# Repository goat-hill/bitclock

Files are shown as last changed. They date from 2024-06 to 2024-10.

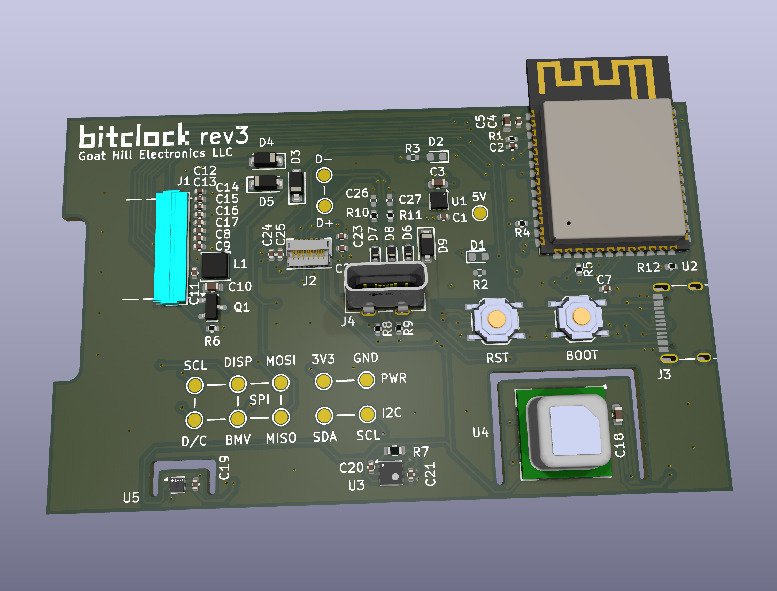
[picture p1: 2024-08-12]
bitclock-pcb/rev3a/pcb.png

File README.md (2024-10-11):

bitclock

# bitclock
Open source e-ink desk companion, clock, and air quality monitor.

Available for purchase in USA @ https://bitclock.io

Bitclock photo

Visit https://bitclock.io/connect to configure your existing device

## Firmware

Source code for ESP32 using the ESP-IDF development framework.

See [bitclock-fw/](bitclock-fw/)

## Website

Next.js web app for [homepage](https://bitclock.io) and [device configurator](https://bitclock.io/connect).

See [bitclock-web/](bitclock-web/)

Web configurator screenshot

## Enclosure

OnShape design, STEP files, and instructions for 3D printing.

See [bitclock-enclosure/](bitclock-enclosure/)

Device CAD screenshot

## PCB

KiCad schematic, board, and JLCPCB ordering files.

See [bitclock-pcb/](bitclock-pcb/)

Bitclock PCB

# Blog posts

- [Advanced ESP32 development with ESP-IDF](https://bitclock.io/blog/esp-idf-vscode)

# Contributing

## Cloning the repo

This repo uses git submodules. Make sure to use `git clone --recursive`.

```sh
git clone --recursive git@github.com:goat-hill/bitclock.git
```

If the repo was previously checked out without `--recursive`, initialize the submodules.

```sh
git submodule init
git submodule update
```

## Pre-commit linting

A single pre-commit config is created for this monorepo. Set up the hooks to get linting on every commit.

```fish
brew install pre-commit
pre-commit install
```

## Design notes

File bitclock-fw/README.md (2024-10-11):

# bitclock firmware

## Bootstrap

### One-time esp-idf setup

[esp-idf](https://github.com/espressif/esp-idf) (the ESP32 development framework) needs to be installed separately before building the firmware.

Bash shell

```fish
brew install cmake ninja dfu-util python@3.12
brew reinstall openssl
git clone -b v5.2.2 --recursive https://github.com/espressif/esp-idf.git
./install.sh esp32s3
source export.sh
```

Fish shell

```fish
brew install cmake ninja dfu-util python@3.12
brew reinstall openssl
git clone -b v5.2.2 --recursive https://github.com/espressif/esp-idf.git
./install.fish esp32s3
source export.fish
```

### Entering esp-idf environment

Bash shell

```sh
source ~/path-to-esp-idf/export.sh
```

Fish shell

```fish
source ~/path-to-esp-idf/export.fish
```

## Target directories

In order to maintain older PCB revision targets, we have separate directories for each PCB revision. Despite most files being shared across targets (via symlinks) we do this because esp-idf doesn't handle multiple targets well. This gives each target it's own build configuration and directory.

```fish
cd target-rev2-esp32s3/
```

To avoid confusing your code editor with duplicate files across targets, it is recommended to open VSCode with a single target as the root directory.

```fish
code .
```

## Build

```fish
idf.py build
```

## Flash

```fish
idf.py flash
```

## Monitor

```fish
idf.py monitor
```

## Debug

```fish
idf.py openocd
```

Then go to VSCode and "Start Debugging" (F5)

## Developer tips

### Bluetooth GATT attributes

If you edit GATT attributes, the web configurator may stop working. This is doing some kind of caching of GATT attributes by service ID.

To resolve the issue, go into Bluetooth settings and "Forget Device", then re-pair it to refresh the GATT cache.

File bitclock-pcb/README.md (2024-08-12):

# bitclock PCB

Each directory includes gerber + BOM files used for ordering from a PCBA service like JLCPCB.

Latest PCB version is [rev3a](rev3a/)

## PCBA ordering scripts

Used for ordering from JLCPCB or MacroFab.

https://github.com/goat-hill/kicad-pcba-scripts

## Revision history

#### rev3a
First version sold on https://bitclock.io/

It does include a few extraneous components that were an attempt to support the unreleased [BMV080](https://www.bosch-sensortec.com/products/environmental-sensors/particulate-matter-sensor/bmv080/) particulate sensor. I may have misinterpreted the preliminary datasheet so feel free to omit that connector and supporting capacitors. It also designs for an option side-USB port that I may omit in the future due to added routing complexity and it is unused.

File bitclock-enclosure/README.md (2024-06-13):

# bitclock enclosure

## CAD design

[OnShape design v6.2](https://cad.onshape.com/documents/f4d7ba303b59b71b8201b0bf/v/8381e401aa08874d26e5d90c/e/d0fdc989a686ce42a3170916)

The 3D printed enclosure STL files can be exported from the "Back plastic" and "Front plastic" parts.

## 3D printing

Print the flat sides down on the bed.

Tested using Prusa Mini+ with PLA and PETG.

Default print settings with 0.2mm Structural mode + input shaping.

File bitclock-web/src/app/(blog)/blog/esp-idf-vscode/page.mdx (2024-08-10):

import NextImage from "next/image";
import { Box, Button, Image, Paper, Title, Kbd } from "@mantine/core";
import InlineVideo from "@/app/(blog)/blog/inline-video";
import InlineImage from "@/app/(blog)/blog/inline-image";
import BitclockBannerImage from "./banner.png";
import BitclockImage from "@/app/img/bitclock.jpg";
import BitclockPcbImage from "@/app/img/pcb.jpg";
import PlatformioImage from "./platformio.png";
import ArduinoCoreImage from "./arduino-core.png";
import FooterImage from "@/app/img/3d-print.jpg";
import GetBitclock from "@/app/(blog)/blog/get-bitclock";

export const metadata = {
  // author: "Brady Law",
  // date: "2024-06-20",
  title: "Advanced ESP32 development with ESP-IDF",
  description: "For electronics projects that outgrow Arduino",
  // bannerImage: BannerImage,
  // tags: ["esp32", "esp-idf", "fimrware"]
};

{
// TODO:
// - Banner image
// - Facebook/Twitter share metadata
// - Post author, date, tags to page
// - Share buttons, Follow on X buttons
// - Code block filenames
// - Static analysis + code completion explanation
// - Interactive debugging explanation
// - Add Bitclock image somwehere
// - Blog navigation and list
}

<Title order={1} mt="xl">
  {metadata.title}
</Title>
<Title order={4} mt="sm" c="dimmed">
  {metadata.description}
</Title>

<Paper shadow="xs" px="md" py="xs" mt="xl">

Many electronics hobbyists begin with the Arduino ecosystem. That's how I got started!

My first project was a tripod mount that could hold an iPhone for filming and pan using a motor. Early iterations used an [Arduino Nano 33 BLE](https://store.arduino.cc/products/arduino-nano-33-ble), a [servo motor](https://www.amazon.com/gp/product/B09BV5D7MD/), and 4x AA batteries.

<InlineVideo
  src="/videos/vscode-arduino.mp4"
  label="Arduino controlling a servo motor"
  loop
  autoplay
/>

When writing firmware for the Arduino Nano, I started with the Android IDE + SDK.

The code for communicating over Bluetooth and controlling the servo fit into a few hundred line `.ino` sketch file.
The wiring was pretty straightforward and only needed a few pins connected. The Arduino [Servo](https://www.arduino.cc/reference/en/libraries/servo/)
library for motor control and [ArduinoBLE](https://www.arduino.cc/reference/en/libraries/arduinoble/) for comms made it easy to implement.

When I finished working on that project, I moved to increasingly complex projects. The [Bitclock](https://bitclock.io) project
needed to connect to an e-ink screen, mount three I2C sensors, and fit into a tiny enclosure.
At this point, I was looking to graduate from the Arduino Nano and hand soldering everything together.

<InlineImage
  src={BitclockImage}
  alt="Bitclock photo"
  label="Bitclock - E-ink clock + air quality monitor"
/>

<GetBitclock />

To meet these requirements, I decided to design a custom PCB (printed circuit board).
By designing a PCB specific to the device, Bitclock electronics could have a smaller footprint that would fit snugly into an enclosure.
Additionally, manufacturing the product at scale would be simplified through PCB assembly services
like 🇨🇳 [JLCPCB](https://jlcpcb.com/), [PCBWay](https://www.pcbway.com/), or 🇺🇸 [MacroFab](https://www.macrofab.com/).

I should disclose that one of my main goals when starting [Bitclock](https://bitclock.io) was to learn custom PCB design,
so my approach was going to end up there anyway!

<InlineImage
  src={BitclockPcbImage}
  alt="Bitclock PCB photo"
  label="Bitclock PCB assembly, featuring an ESP32-S3 microcontroller"
  priority
/>

An early question when designing [Bitclock](https://bitclock.io) was which microcontroller to use.

I settled on the [ESP32-S3](https://www.espressif.com/en/products/socs/esp32-s3) module, which you can see mounted to the top-right corner of the PCB. These ESP32 SoC (system-on-a-chip) modules are popular for a few reasons:

- **All-in-one**: Built-in Wi-Fi, Bluetooth, and flash simplifies PCB design
- **Low price**: Modules starting at [~$1](https://www.digikey.com/en/products/detail/espressif-systems/ESP32-C3-MINI-1-N4/13877574), dev boards for [~$10](https://www.amazon.com/Seeed-Studio-XIAO-ESP32C3-Microcontroller/dp/B0B94JZ2YF/)
- **USB support**: Can be powered, flashed, and debugged over USB
- **SDK**: Extensive development framework with high quality [documentation](https://docs.espressif.com/projects/esp-idf/en/stable/esp32/index.html)
- **Low power**: Can operate in the 10s of mA, sleep in µA range
- **Pre-certification**: [Pre-certified](https://www.espressif.com/en/support/documents/certificates) by FCC and others making products easier to sell

With the [Bitclock](https://bitclock.io) project, my firmware grew to [thousands of lines](https://github.com/goat-hill/bitclock/tree/master/bitclock-fw/main) and many files.
The firmware needed to render graphics for a display, communicate over bluetooth + Wi-Fi, communicate with sensors.
These features needed to multi-task on a single core and meet the constrained memory & flash of the ESP32.

While you can technically write code for ESP32 using the Arduino IDE + SDK, I settled on an alternative approach for this project
using Espressif's [**ESP-IDF framework**](https://github.com/espressif/esp-idf).

### Switching to ESP-IDF

Technically, you _can_ program an ESP32 using Arduino IDE & SDK.

The generic Arduino toolchain supports different hardware platforms through [**Arduino Cores**](https://github.com/arduino/ArduinoCore-API).
Each Arduino Core implements the standard APIs like [Serial](https://www.arduino.cc/reference/en/language/functions/communication/serial/) and [Wire](https://www.arduino.cc/reference/en/language/functions/communication/wire/).
In the case of ESP32 devices, Espressif
actively maintains the [arduino-esp32](https://github.com/espressif/arduino-esp32) core implementation.

Under the hood, the [arduino-esp32](https://github.com/espressif/arduino-esp32) core is largely implemented using the [**ESP-IDF framework**](https://github.com/espressif/esp-idf).
The ESP-IDF framework was developed specifically for ESP32 SoCs, and has many features and APIs specific to that family of devices.

<InlineImage
  src={ArduinoCoreImage}
  alt="Demonstration of Arduino leveraging ESP-IDF"
  label="arduino-esp32 is implemented using ESP-IDF"
/>

This brought about a major design decision for [Bitclock](https://bitclock.io). Continue using the generic and familiar Arduino SDKs, or switch to the manufacturer's ESP-IDF framework?

- ✅ Arduino is a familiar SDK
- ✅ Arduino is compatible with different hardware
- ✅ Arduino can be lower effort to bootstrap using the IDE
- ❌ Arduino core abstraction layer means more code. Extra code could lead to unnecessary complexity and bugs.
- ❌ Arduino cores cannot make ESP32-specific assumptions. This could make precise device control more difficult.

For the Bitclock project, hardware cross-compatibility was not a priority. Instead, hardware _control_ was more important especially given the hardware constraints of:

- 400kB memory
- 8 MB flash
- Single core to multi-task display + sensors + networking

On the other hand, the ESP-IDF framework offers equivalent [high and low level APIs](https://docs.espressif.com/projects/esp-idf/en/latest/esp32/api-reference/index.html), and is very well documented.

Some of the ESP-IDF features Bitclock leverages include:

- [freertos](https://docs.espressif.com/projects/esp-idf/en/stable/esp32/api-reference/system/freertos.html) - Multi-threading for better display performance
- [ota](https://docs.espressif.com/projects/esp-idf/en/stable/esp32/api-reference/system/ota.html) - OTA firmware updates via Wi-Fi or bluetooth
- [partitions](https://docs.espressif.com/projects/esp-idf/en/stable/esp32/api-guides/partition-tables.html) - For custom layouts of flash memory
- [bt](https://docs.espressif.com/projects/esp-idf/en/stable/esp32/api-reference/bluetooth/index.html) - Bluetooth + BLE applications

Given the above, I decided to use ESP-IDF directly and bypass the Arduino abstraction.

### Switching to VSCode

While I had enjoyed using the Arduino IDE previously, it no longer seemed the obvious choice given the ESP-IDF choice. VSCode was the general code editor I used the most, and has many appealing features:

- Strong IDE support for [C and C++ development](https://marketplace.visualstudio.com/items?itemName=ms-vscode.cpptools)
- Performant and streamlined text editor
- As opposed to Arduino IDE: better support for files and directories
- Free. Corporate backing by Microsoft
- Integrates Github Copilot which can [speed up development](https://github.blog/2022-09-07-research-quantifying-github-copilots-impact-on-developer-productivity-and-happiness/)

In order to make the switch to VSCode, it was necessary to ensure that I would have replacements for a few crucial Arduino IDE features:

1. Compile + flash + serial log monitoring
2. Static code analysis + code completion
3. Interactive GDB debugging

[PlatformIO](https://platformio.org/) is a popular VSCode extension that supports all of these features, so I experimented with that before ultimately deciding not to use it and instead configure VSCode manually.

#### Evaluating PlatformIO

On paper, PlatformIO supported all the features I wanted for embedded development in VSCode. I'd be able to compile, flash, debug, and get static analysis of my code.

However, after installing the extension I was less enthused. I was greeted with a landing page showing news, social links, and project creation wizards. It's certainly a personal preference, but PlatformIO was delivering me an entire IDE-within-IDE when I was looking for a few basic debugging and code highlighting features.

<InlineImage
  src={PlatformioImage}
  alt="PlatformIO screenshot"
  label="VSCode after PlatformIO extension installed"
/>

Fortunately, there is an alternative way to get the functionality I desired using only VSCode, the [C/C++ extension by Microsoft](https://marketplace.visualstudio.com/items?itemName=ms-vscode.cpptools), and the [ESP-IDF](https://github.com/espressif/esp-idf) CLI toolchain.

### ESP-IDF toolchain setup

The ESP-IDF toolchain includes the SDK, as well as a [command line front-end](https://docs.espressif.com/projects/esp-idf/en/stable/esp32/api-guides/tools/idf-py.html) for `build`, `flash`, and `monitor`.
If you use PlatformIO it likely installs it for you, but since we're doing things manually we'll install it ourselves.

Follow the [instructions from Espressif here](https://docs.espressif.com/projects/esp-idf/en/stable/esp32/get-started/linux-macos-setup.html).

On macOS, you'll need create a directory to install the SDK to and the process goes something like this:

```sh
brew install cmake ninja dfu-util python3
git clone -b v5.3 --recursive https://github.com/espressif/esp-idf.git
./install.fish esp32s3
source export.sh
```

Make sure to read the [latest docs](https://docs.espressif.com/projects/esp-idf/en/stable/esp32/get-started/linux-macos-setup.html) for up-to-date installation instructions.

### ESP-IDF project bootstrapping

With the toolchain now installed, create a separate directory to house the source code of your new project.

You can use ESP-IDF frontend to create a barebone project for you:

```sh
source ~/your/path/to/esp-idf/export.sh
idf.py create-project example
```

This will create a directory structure with the following:

```text
├── CMakeLists.txt          Top-level build configuration
├── main
│   ├── CMakeLists.txt      Defines main build target + dependencies
│   └── example.c           Main run function for app
```

Make sure to tell ESP-IDF what device you are building for:

```sh
idf.py set-target esp32s3
```

With that complete, build and run is a simple via the CLI:

- `idf.py build`
- `idf.py flash`
- `idf.py monitor`

### Static analysis + code completion

The ESP-IDF CLI tool solves build + run, but for VSCode to be a real IDE™️ it needs to know where to look for ESP-IDF libraries referenced by your code.

We'd need code static analysis to get library auto-completion, CMD+click to jump to function definitions, and a red squiggly underlines when we add a bug.

<InlineVideo
  src="/videos/vscode-completion.mp4"
  autoplay
  loop
  label="Auto-completion from ESP-IDF SDK"
/>

First, make sure you have the [C/C++ extension](https://marketplace.visualstudio.com/items?itemName=ms-vscode.cpptools) by Microsoft installed.

Then we can [configure IntelliSense](https://code.visualstudio.com/docs/cpp/customize-default-settings-cpp) by adding a `.vscode/c_cpp_properties.json` file to the root of the project. VSCode will read this to configure the extension.

Here's an example that worked for Bitclock's ESP32-S3 on macOS:

```json
{
  "env": {
    "esp-version": "esp-13.2.0_20240530"
  },
  "configurations": [
    {
      "name": "esp32s3",
      "compilerPath": "${HOME}/.espressif/tools/xtensa-esp-elf/${esp-version}/xtensa-esp-elf/bin/xtensa-esp-elf-gcc",
      "compileCommands": "${workspaceFolder}/build/compile_commands.json",
      "includePath": [
        "${HOME}/.espressif/tools/xtensa-esp-elf/${esp-version}/xtensa-esp-elf/xtensa-esp-elf/include/**",
        "${HOME}/code/esp-idf/components/**",
        "${workspaceFolder}/**"
      ],
      "browse": {
        "path": [
          "${HOME}/.espressif/tools/xtensa-esp-elf/${esp-version}/xtensa-esp-elf/xtensa-esp-elf/include/**",
          "${HOME}/code/esp-idf/components/**",
          "${workspaceFolder}/**"
        ],
        "limitSymbolsToIncludedHeaders": false
      }
    }
  ],
  "version": 4
}
```

It does the following:

- Sets `.compilerPath` to point to the GCC compiler used for the project
- Sets `.compileCommands` to hint to IntelliSense the specific arguments for how each file was last compiled
- Sets `.includePath` to include the core libraries for IntelliSense, [component](https://docs.espressif.com/projects/esp-idf/en/stable/esp32/api-guides/build-system.html) libraries, and your project workspace
- Sets `.browse.path` to include same libraries for the ["Tag Parser" of VSCode](https://code.visualstudio.com/docs/cpp/faq-cpp#_what-is-the-difference-between-includepath-and-browsepath)

Make sure the paths match the locations of ESP-IDF's install location and `~/.espressif` workspace for your system. See the ESP-IDF [tools.json](https://github.com/espressif/esp-idf/blob/master/tools/tools.json) to see what version you should be pointing to. For example, ESP32-S3 uses the `xtensa-esp-elf` compiler while ESP32-C3 uses `riscv32-esp-elf`.

To be honest, I'm not entirely sure how critical each of these fields is to IntelliSense but I do know that in its entirety the configuration worked for my project!
I used the [Espressif's VSCode extension](https://github.com/espressif/vscode-esp-idf-extension/blob/master/docs/C_CPP_CONFIGURATION.md) as a guide (yet another VSCode extension that I opted to skip and configure manually 🧘).

### Interactive debugging

Last but not least, we'd like to have GDB functionality within VSCode. The `C/C++` extension we've already installed supports this but we need to tell it how to connect.

<InlineVideo
  src="/videos/vscode-debug.mp4"
  autoplay
  loop
  label="ESP32 interactive debugging using OpenOCD"
/>

For Bitclock, the following [debugging configuration](https://code.visualstudio.com/docs/cpp/launch-json-reference) worked by this file to your project's `.vscode/launch.json`:

```json
{
  "version": "0.2.0",
  "configurations": [
    {
      "name": "esp-openocd",
      "type": "cppdbg",
      "request": "launch",
      "program": "${workspaceFolder}/build/example.elf",
      "MIMode": "gdb",
      "miDebuggerPath": "/full/path/to/.espressif/tools/xtensa-esp-elf-gdb/14.2_20240403/xtensa-esp-elf-gdb/bin/xtensa-esp32s3-elf-gdb",
      "cwd": "${workspaceFolder}",
      "setupCommands": [
        { "text": "target extended-remote :3333" },
        { "text": "set remote hardware-watchpoint-limit 2" },
        { "text": "mon reset halt" },
        { "text": "maintenance flush register-cache" },
        { "text": "thb app_main" }
      ]
    }
  ]
}
```

Make sure `.miDebuggerPath` points to the correct ESP-IDF toolchain for this project (see `tools.json` tip from above). Also ensure `.program` points to the `.elf` build of your project.

Once setup, connect your ESP32 hardware, flash it with the latest version of your app, and start the local [OpenOCD](https://openocd.org/) server. This will start a debugging connection over USB with your device:

```sh
idf.py openocd
```

The last step is to connect VSCode to your debugging session. Open the **Run & Debug Panel** (on macOS: <Kbd>⌘</Kbd> + <Kbd>Shift</Kbd> + <Kbd>D</Kbd>), then the click the ▶️ button to start debugging (<Kbd>F5</Kbd>).
VSCode allows you to visually set breakpoints, inspect memory, and the usual debugging IDE features you'd expect.

### Parting thoughts

For projects that grow too complex for the Arduino ecosystem, consider switching to ESP-IDF & VSCode.
If you take that path, I hope this write-up proves a helpful resource in getting things going.

<InlineImage src={FooterImage} alt="Bitclock photo" />

There is more I'd love to share from working on this project. Topics include:

- PCB and 3D printed enclosure design
- Multi-threaded apps with freertos
- Working with e-ink displays and LVGL graphics

If you've got feedback, or want to see anything specifically described further, don't hesitate to reach out at [brady@bitclock.io](mailto:brady@bitclock.io)!

And if you're interested in the gadget that inspired this post, consider ordering a Bitclock!
Either use it as clock + air quality monitor, or write your own apps. The code is [open source on GitHub](https://github.com/goat-hill/bitclock).

<GetBitclock />

Happy hacking...

--Brady

</Paper>

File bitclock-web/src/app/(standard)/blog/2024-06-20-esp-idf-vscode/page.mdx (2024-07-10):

import NextImage from "next/image";
import { Image } from "@mantine/core";
import BannerImage from "./banner.png";
import { Box, Paper, Title } from "@mantine/core";
import InlineVideo from "@/app/(standard)/blog/inline-video";
import BitclockImage from "./banner.png";

export const metadata = {
  // author: "Brady Law",
  // date: "2024-06-20",
  title: "ESP32 development with ESP-IDF & VSCode",
  description: "Tips for projects that outgrow the Arduino SDK",
  // bannerImage: BannerImage,
  // tags: ["esp32", "esp-idf", "fimrware"]
};

{
// TODO:
// - Banner image
// - Facebook/Twitter share metadata
// - Post author, date, tags to page
// - Share buttons, Follow on X buttons
// - Code block filenames
// - Static analysis + code completion explanation
// - Interactive debugging explanation
// - Add Bitclock image somwehere
// - Blog navigation and list
}

<Title order={1} mt="xl">
  {metadata.title}
</Title>
<Title order={4} mt="sm" c="dimmed">
  {metadata.description}
</Title>

<Image
  component={NextImage}
  src={BitclockImage}
  w="100%"
  width={928}
  h="auto"
  alt="Bitclock photo"
  radius="md"
  fit="contain"
  mt="md"
/>

<Paper shadow="xs" px="md" py="xs" mt="xl">
Hobbyist electronics projects are increasingly turning to the ESP32 SoC (System-on-a-Chip) to control their devices. [Bitclock](https://github.com/goat-hill/bitclock) is no exception, and features an [ESP32-S3-WROOM-1](https://www.digikey.com/en/products/detail/espressif-systems/ESP32-S3-WROOM-1-N8/15200089) module mounted to the board.

These modules are popular for a number of reasons:

- **Simplicity**: Built-in Wi-Fi, Bluetooth, and flash on a single module
- **Low price**: Modules for [~$1](https://www.digikey.com/en/products/detail/espressif-systems/ESP32-C3-MINI-1-N4/13877574), dev boards for [~$10](https://www.amazon.com/Seeed-Studio-XIAO-ESP32C3-Microcontroller/dp/B0B94JZ2YF/)
- **SDK**: Extensive development framework and high quality [documentation](https://docs.espressif.com/projects/esp-idf/en/stable/esp32/index.html)
- **Low power consumption**: Can operate in the 10s of mA or sleep in µA
- **Pre-certification**: [Pre-certified](https://www.espressif.com/en/support/documents/certificates) by FCC and others so it's easier to sell

### Outgrowing the Arduino SDK

Most ESP32 tutorials begin with installing the Arduino IDE. It's popular because it only takes a few steps to get a running "Hello World" or blinking LED. The IDE automatically downloads an ESP32 SDK and has a simple but comprehensive interface for getting started.

However, more complex ESP32 projects can quickly overwhelm the constraints of single Arduino sketch file. The Arduino IDE + SDK is efficient for bootstrapping projects but is **not the best fit for more advanced ESP32 projects.**

When exploring development environments for Bitclock, I had a few objectives:

#### 1. Remove unnecessary abstractions

When using the Arduino IDE, you are tied to using the [arduino-esp32](https://github.com/espressif/arduino-esp32) SDK and the Arduino [programming language](https://www.arduino.cc/reference/en/).

The [arduino-esp32](https://github.com/espressif/arduino-esp32) SDK is an abstraction on top of the ESP32-specific [ESP-IDF](https://github.com/espressif/esp-idf) SDK. While there are some advantages to using an abstract Arduino SDK that can port to non-ESP32 board types, complex applications will benefit from using the [ESP-IDF](https://github.com/espressif/esp-idf) framework directly and optimizing for the hardware selceted for the project.

The ESP-IDF framework is packed with features and is extremely well documented. Some features [Bitclock](https://github.com/goat-hill/bitclock) leverages include:

- [freertos](https://docs.espressif.com/projects/esp-idf/en/stable/esp32/api-reference/system/freertos.html) - Multi-threading and better display performance
- [ota](https://docs.espressif.com/projects/esp-idf/en/stable/esp32/api-reference/system/ota.html) - OTA firmware updates via Wi-Fi or bluetooth
- [partitions](https://docs.espressif.com/projects/esp-idf/en/stable/esp32/api-guides/partition-tables.html) - For custom layouts of flash memory
- [bt](https://docs.espressif.com/projects/esp-idf/en/stable/esp32/api-reference/bluetooth/index.html) - Bluetooth + BLE applications

By using a generic IDE instead of Arduino, we can start using the ESP-IDF SDK instead.

#### 2. Use a popular IDE

VSCode is already a popular choice for backend, web, and embedded software development. It has strong IDE support for development in C and C++. It is free, extremely performant, and the backing of Microsoft to keep it working well. It also integrates with Github Copilot which can [speed up certain development tasks](https://github.blog/2022-09-07-research-quantifying-github-copilots-impact-on-developer-productivity-and-happiness/).

And last but not least, it makes it easy for your project to have more than one source file! 😀

Before switching to using ESP-IDF + VSCode environment, I wanted to validate that the following developer features would still be available:

1. **Simple build + run + monitor**
2. **Static analysis + code completion**
3. **Interactive debugging**

In the sections below, I'll show how this functionality is preserved.

#### \* - A note on PlatformIO

[PlatformIO](https://platformio.org/) is a popular project for ESP32 development within VSCode.

I first evaluated using that, but I did not find that it met the first requirement of _Minimize abstractions_. The VSCode extension it requires adds a lot of visual and functional bloat to the VSCode editor that I found unnecessary through the setup described later in this post.

### ESP-IDF toolchain setup

To start a project with ESP-IDF, you'll first need to install the ESP-IDF toolchain. Follow the [instructions on the Espressif website here](https://docs.espressif.com/projects/esp-idf/en/stable/esp32/get-started/linux-macos-setup.html).

On macOS, you'll need create a directory to install the SDK to and the process goes something like this:

```sh
brew install cmake ninja dfu-util python@3.12 openssl
git clone -b v5.2.2 --recursive https://github.com/espressif/esp-idf.git
./install.fish esp32s3
source export.sh
```

Make sure to select the latest release version of ESP-IDF, the board you are using in place of `esp32s3` and read their docs for the latest instructions.

### Basic project setup

Create a separate new directory to house your project source code.

See the [ESP-IDF Hello World](https://github.com/espressif/esp-idf/tree/v5.2.2/examples/get-started/hello_world) example for the basic project setup.

The file structure will start with the following:

```text
├── CMakeLists.txt
├── pytest_hello_world.py      Python script used for automated testing
├── main
│   ├── CMakeLists.txt
│   └── hello_world_main.c
```

Once your project is created, and the ESP-IDF environment is active via `source ~/esp-idf/export.sh`, build and run is a simple via the CLI:

- `idf.py build`
- `idf.py flash`
- `idf.py monitor`

The [Hello World example](https://github.com/espressif/esp-idf/tree/v5.2.2/examples/get-started/hello_world) does a good job of giving the basics of how an ESP-IDF project is organized, so this post will focus on other topics.

### Static analysis + code completion

<InlineVideo
  src="/videos/vscode-completion.mp4"
  autoplay
  loop
  label="Auto-completion from ESP-IDF SDK"
/>

```json
{
  "env": {
    "esp-version": "esp-13.2.0_20230928"
  },
  "configurations": [
    {
      "name": "esp32s3",
      "compilerPath": "${HOME}/.espressif/tools/xtensa-esp-elf/${esp-version}/xtensa-esp-elf/bin/xtensa-esp-elf-gcc",
      "compileCommands": "${workspaceFolder}/build/compile_commands.json",
      "includePath": [
        "${HOME}/.espressif/tools/xtensa-esp-elf/${esp-version}/xtensa-esp-elf/xtensa-esp-elf/include/**",
        "${HOME}/code/esp-idf/components/**",
        "${workspaceFolder}/**"
      ],
      "browse": {
        "path": [
          "${HOME}/.espressif/tools/xtensa-esp-elf/${esp-version}/xtensa-esp-elf/xtensa-esp-elf/include/**",
          "${HOME}/code/esp-idf/components/**",
          "${workspaceFolder}/**"
        ],
        "limitSymbolsToIncludedHeaders": false
      },
      "defines": ["BOARD_TARGET=2"]
    }
  ],
  "version": 4
}
```

### Interactive debugging

<InlineVideo
  src="/videos/vscode-debug.mp4"
  autoplay
  loop
  label="GDB interactive debugging using OpenOCD"
/>

```sh
idf.py openocd
```

```json
{
  "version": "0.2.0",
  "configurations": [
    {
      "name": "esp-openocd",
      "type": "cppdbg",
      "request": "launch",
      "program": "${workspaceFolder}/build/bitclock.elf",
      "MIMode": "gdb",
      "miDebuggerPath": "/Users/bradylaw/.espressif/tools/xtensa-esp-elf-gdb/12.1_20231023/xtensa-esp-elf-gdb/bin/xtensa-esp32s3-elf-gdb",
      "cwd": "${workspaceFolder}",
      "setupCommands": [
        { "text": "target extended-remote :3333" },
        { "text": "set remote hardware-watchpoint-limit 2" },
        { "text": "mon reset halt" },
        { "text": "maintenance flush register-cache" },
        { "text": "thb app_main" }
      ]
    }
  ]
}
```

Show how to attach in VSCode, set breakpoints, print values.

### Custom PCB design tips

Do not add a USB-to-UART, it is built-in to ESP32-S3 + ESP32-C3

Buttons are not required for switching to BOOT mode.

Don't forget strapping pins and pull-up resistors.

### Multi-target repo organization

```text
├── bitclock-fw/
│   ├── components/
│   ├── main/
│   ├── target-board-v1/
│   ├── target-board-v2/
│   ├── partitions.csv
│   └── sdkconfig.defaults
```

#### bitclock-fw/target-board-v2/

**Source files**

```text
├── .vscode/
│   ├── c_cpp_properties.json
│   ├── launch.json
│   └── settings.json
├── CMakeLists.txt
├── dependencies.lock
├── sdkconfig
```

**Symlinks**

```text
├── components/
├── main/
├── partitions.csv
```

**Auto-generated files**

```text
├── sdkconfig
├── dependencies.lock
```

### Parting thoughts

In this post, we outlined how to set up a development environment for an ESP32 project using ESP-IDF and VSCode instead of the more restrictive Arduino IDE.

In future posts we'll go into:

- Multi-threaded apps with freertos
- Working with e-ink displays and LVGL graphics
- Designing custom PCBs to fit 3D printed enclosures

In the meantime, send any comments or development tips to brady@bitclock.io!

Also if you're interested in a cute desk clock + air quality monitor for your desk that inspired this post, order one at [bitclock.io](https://bitclock.io).
It's completely open source and a fun hackable device to get started with ESP32 development.

</Paper>

by Brady Law

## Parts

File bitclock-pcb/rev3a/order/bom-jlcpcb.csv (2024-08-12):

Comment | Designator | Footprint | JLCPCB Part #
TestPoint | TP1,TP2,TP3,TP4,TP5,TP6,TP7,TP8,TP9,TP10,TP11,TP12,TP13 | TestPoint_Pad_D1.5mm
100nF | C4,C8,C19 | C_0402_1005Metric | C1525
0Ω | R10,R11 | R_0402_1005Metric | C17168
4.7µF | C10 | C_0603_1608Metric | C19666
AO3400A | Q1 | SOT-23 | C20917
4.7Ω | R7 | R_0603_1608Metric | C23164
2.2µF | C3 | C_0603_1608Metric | C23630
10kΩ | R1,R12 | R_0402_1005Metric | C25744
5.1kΩ | R4,R5,R8,R9 | R_0402_1005Metric | C25905
10pF | C7 | C_0402_1005Metric | C32949
1µF | C1,C2,C9,C11,C12,C13,C14,C15,C16,C17,C20,C21,C22,C23,C24,C25 | C_0402_1005Metric | C52923
1N5819HW-7-F | D3,D4,D5,D9 | D_SOD-123 | C82544
10µF | C5,C18 | C_0603_1608Metric | C96446
470mΩ | R6 | R_0402_1005Metric | C158958
600mA 10uH ±20% SPH3010H100MT | L1 | L_Sunlord_SWPA3010S | C279861
SW_Push | SW1,SW2 | SW_Push_1P1T_XKB_TS-1187A | C318884
FH34SRJ-24S-0.5SH | J1 | HRS_FH34SRJ-24S-0.5SH_99_ | C324726
LESD5D5.0CT1G | D6,D7,D8 | D_SOD-523 | C383211
ECT818001568 | J2 | FPC-SMD_ECT818001568 | C711417
TLV76733DRVT | U1 | WSON-6-1EP_2x2mm_P0.65mm_EP1x1.6mm | C2867572
SHT40-AD1B-R2 | U5 | Sensirion_DFN-4_1.5x1.5mm_P0.8mm_SHT4x_NoCentralPad | C2909890
ESP32-S3-WROOM-1-N8 | U2 | ESP32-S3-WROOM-1 | C2913198
TYPE-C 16PLC-H10.0 | J4 | TYPE-C-TH_16PLC-H10.0 | C3151747
SGP41-D-R4 | U3 | XDCR_SGP41-D-R4 | C3659325
SCD40-D-R2 | U4 | Sensirion_SCD4x-1EP_10.1x10.1mm_P1.25mm_EP4.8x4.8mm | C3659421

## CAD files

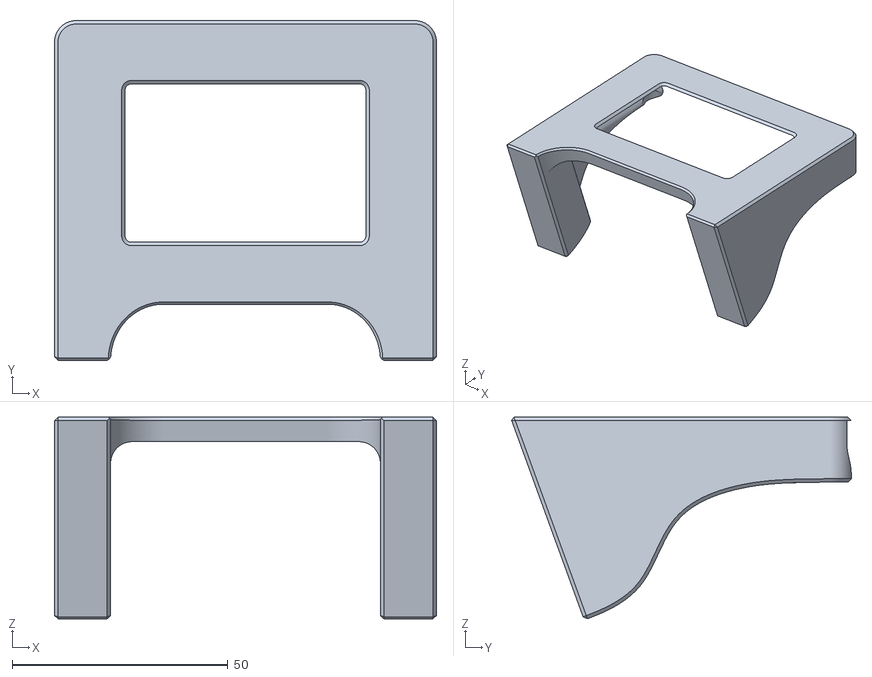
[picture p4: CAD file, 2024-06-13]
bitclock-enclosure/v6.2/front.stl
88.5 x 78.7 x 46.7

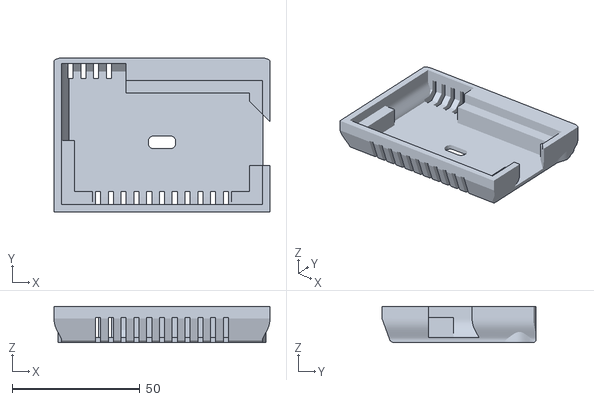
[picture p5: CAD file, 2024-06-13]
bitclock-enclosure/v6.2/back.stl
84.5 x 60.2 x 14.1

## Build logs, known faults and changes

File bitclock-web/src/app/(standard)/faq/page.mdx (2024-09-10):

### How do I power my Bitclock?

The device is powered via a USB-C port, any USB cable that can connect with USB-C on one side should work.

It is recommended that you power it from an always-on power source: either a wall adapter from an old iPhone, a desktop, etc.

Device is very low power so any power source rated for at least 250mA @ 5V (> 1.25W) will suffice.

### How do I set up my new Bitclock?

If assembling the device yourself, the e-ink display may still have a protective film so make sure to peel that off before inserting it into the enclosure.

Once assembled, power the device with a USB-C cable and connect to it by visiting [bitclock.io/connect](/connect) in Google Chrome on a desktop/laptop.

From there, input your Wi-Fi credentials so the device can connect to the internet and sync clocks + weather.

The configuration tool uses Web Bluetooth to communicate to the Bitclock. Make sure Bluetooth on your computer is enabled.

Many browsers, including most mobile browsers, [don't support Web Bluetooth](https://developer.mozilla.org/en-US/docs/Web/API/Web_Bluetooth_API#browser_compatibility), so you'll need to use Google Chrome for macOS/Windows.

### Is it difficult to 3D print the enclosure myself?

No, in fact it should be very easy to print on a properly tuned 3D printer! You can find the STL files and printing tips on [GitHub](https://github.com/goat-hill/bitclock/tree/master/bitclock-enclosure).

It takes around 2 hours on a Prusa Mini+, and the print is relatively simple with no supports. I've tested many prints with PETG and the prints have been reliable.

Make sure the Z adjustment for the first layer is [properly tuned](https://help.prusa3d.com/article/live-adjust-z_112427) since that will be the visible front of the Bitclock.

### How do I make a custom clockface app?

This is a bit complicated at the moment, but in the future I hope to make this much more approachable and documented! Here is some info in the meantime.

Bitclock leverages [FreeRTOS](https://www.freertos.org/) for multi-tasking. A display task is responsible for controlling the e-ink display.

The display task is defined in [eink_display.c](https://github.com/goat-hill/bitclock/blob/master/bitclock-fw/main/tasks/eink_display.c), and utilizes [LVGL](https://github.com/lvgl/lvgl) to render what appears on the display.

LVGL views are defined in the [lvgl/](https://github.com/goat-hill/bitclock/tree/master/bitclock-fw/main/lvgl) directory.

If your clockface requires networking or some other background work, I suggest creating a separate task for that logic. See the [weather.c](https://github.com/goat-hill/bitclock/blob/master/bitclock-fw/main/tasks/weather.c) task as an example of making regular background network requests.

### How accurate are the sensors?

Bitclock uses three Sensirion factory calibrated sensors. See below for their reported accuracy.

Device self-heating impacts temperature and relative humidity readings.
To mitigate this, temperature and relative humidity are adjusted based on consistent [offsets](https://github.com/goat-hill/bitclock/blob/a495f9582fb3601ba604b6d4db3fd6bbdfef9350/bitclock-fw/main/tasks/sht4x.c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) observed during testing.

If Bitclock is not in normal operation (consistently on and connected to Wi-Fi) you may observe inaccurate measurements. If you tweak the code and the device uses more or less power, this can also slightly impact sensor accuracy.

VOC, NOx, and CO2 readings are relative sensors that auto-calibrate over time to the surrounding environment. The CO2 sensor, for example, expects "fresh air" levels of CO2 at least once per week and calibrates to that level.

Sensor details from Sensirion:

- [SHT40 ±1.8% / max. ±3.5% RH Digital humidity and temperature sensor](https://sensirion.com/products/catalog/SHT41)
- [SCD40 CO₂ accuracy of ±(50 ppm + 5% MV) @400-2000 ppm](https://sensirion.com/products/catalog/SCD40)
- [SGP41 VOC and NOx sensor](https://sensirion.com/products/catalog/SGP41)

### Can the device be battery powered?

At the moment, no. The enclosure, PCB, and software all assume USB as the source of power.

The device runs at a pretty lower power usage (\~0.25W) so it could be tweaked in the future.

### Why does it not have a PM2.5 particulate sensor?

Wildfires are a growing concern here in California and I'd love to add a particulate sensor.

Unfortunately, particulate sensors like the [Plantower PM2.5 sensor](https://learn.adafruit.com/pm25-air-quality-sensor/overview) have very large form factors and
I decided to omit them from the current design.

My hope is in the future there will be cheap sensors with a smaller form factor, like the unreleased [BMV080](https://www.bosch-sensortec.com/products/environmental-sensors/particulate-matter-sensor/bmv080/).

In fact, there is a port on the Bitclock based on preliminary datasheets from that sensor! If it ever releases and is accurate, I'd like to integrate it in the future.

### Why is this thing so expensive?

The e-ink display and CO2 sensor components alone cost $30 per unit. Alternative CO2 sensors products typically cost well over $100.

There's also low volume PCB assembly costs, as well as 3D printing.

### Can I place the Bitclock somewhere not at a desk?

Of course, although keep in mind the display size, viewing angle, and font sizes were picked with a desk setup in mind.

At longer viewing distances beyond a few feet, it can be difficult to read some of the smaller text.

### Does it have a backlight?

No, the display requires an external light source. In future versions I'll consider adding a backlight but the current version doesn't include one.

### Does the device integrate with Apple HomeKit / Google Home / Alexa...

Not yet, but I'd like to add that with a future software update!

It would be great to integrate this with home automation to turn on fans, AC, etc.

### What is the e-ink display like, and why does it use one?

Similar to an Amazon Kindle, the device has an e-ink display that operates by reflecting external light vs emitting light itself. This gives the device a
very natural aesthetic that looks more like paper as opposed to a bright and distracting display.

Each pixel is 1 bit color (black or white), although you can simulate some grays through dithering.

The display can be updated in two ways: a "fast update" which immediately updates only certain pixels or a "full refresh" which blinks the entire display between
black and white for the cleanest update.

While "fast updates" are the least distracting, but over time they can lead to "ghosting" where pixels are not cleanly reset. That's where an occassional "full refresh" where the screen blinks between black and white to cleanly reset the display and show the clearest image.

### How does the device feel?

The 3D printed enclosure is extremely light, under 0.2 lbs or ~60g. I've tried to make an attractive looking device, but it can still have an unavoidable "prototype" feel due to the nature of 3D printing as opposed injection molding or using heavier materials.

There are some visible layer layer lines, and the front and back have a textured surface from the textured plate it prints on.

### Other questions, comments, feedback?

Please ask! Reach me at brady@bitclock.io

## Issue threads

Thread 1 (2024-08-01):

Modify SCD40 calibration periods #46

babldev, 2024-08-01:
Currently set_automatic_self_calibration_initial_period defaults to 44 hours. But that assumes one read every 5 minutes and we read every 5 seconds.

So for "default" behavior we should probably multiply this value by 60. Needs to be sent on boot.

Also scale set_automatic_self_calibration_standard_period in the same fashion

babldev, 2024-08-04:
Nevermind, this only applies to single shot measurement modes. we're not using that

Closed 2024-08-04.

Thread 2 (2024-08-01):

Bluetooth attribute for inverted colors

babldev, 2024-08-01:
Currently it's a build flag only. Give a bluetooth option so you can easily switch to dark mode.

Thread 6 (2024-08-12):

Mainboard link is 404

meron1122, 2024-08-12:
Hi, mainboard link from readme.md causes 404.

babldev, 2024-08-12:
I went ahead and uploaded the rev3a design today https://github.com/goat-hill/bitclock/tree/master/bitclock-pcb/rev3a

I wasn't sure if I wanted to immediately open source the PCB design until I finished selling a first batch here https://bitclock.io/order

But given I don't ship outside of the USA so I don't have to work through the regulatory stuff I decided to open source it in case others want to order! I included ordering files from JLCPCB.

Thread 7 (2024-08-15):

ESP32-C3 version with 18650 battery + charger

handmade0octopus, 2024-08-15:
Hello!
I must say you inspired me a little. Was thinking of making project like this for very long time but never had time to figure which eInk screens would work best and get drivers working.

I spent the night and big part of today to get basic schematic in.

Ideas that I incorporated:
1. Biggest change is swap MCU to one that is less power hungry - namely ESP32-C3 which also has smaller footprint. We utilize 99% of pins on current design with 1 spare pin for extra stuff.

2.  Use single 4.2v cell that will be power source with boost converter + timer controller that is selectable with dip switches to allow for configuration to wakeup at different intervals (from every ~45s up to 30 min - but it can be easily extended from 1s to 2h) or disable sleep completely if needed. Question there is if sensors need some time after powerup to get accurate readings, but because they will be disabled board will have neutral temperature. In general this should allow for super low power draw.

3. USB-C allows for safe charging of the battery. I based design of TP4056 module with overvoltage + undervoltage protection of battery, we can use analog input to measure battery voltage - there is also an option to put input for solar panel as charger will allow for that. Typical 6V solar panel should be enough although I never played with them so any tips are appreciated. Charging current is limited to around 250 mA. While USB-C is connected device will be always powered. LEDs will indicate status of charging and battery.

4. I recreated design in EasyEDA pro and will be happy to share it. I can't stand KiCad I am sorry :( 95% of resistors, capacitors, mosfets etc. are basic parts so should be fairly cheap to purchase and assemble from JLCPCB.

5. I changed temperature and humidity module to TI HDC1080 as it seems to be more accurate. Although this is just preference as they seem to be more accessible.

PCB is not done yet but I had few ideas on making footprint much smaller, but before proceeding I wanted to clarify few things about design and agree on some basics stuff. I know that battery support was requested by many people. Hence I would advise to create Discord server for discussion/ideas and quick development (I can help you set it up etc.)

Currently biggest problem is supply of screens, but if we are serious about I can get some higher quantities ordered if I ask my Chinese suppliers nicely ( ͡º ͜ʖ͡º)

Here is screenshot of early schematic/idea draft:
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

babldev, 2024-08-15:
Thanks for sharing your project!

I actually used the ESP32-C3 initially. Specifically the ESP32-C3-MINI-1 with 4 MB Flash Memory and 400kB SRAM. I was hitting the limits of both sooner than I liked. It was barely enough memory for Bluetooth and Wi-Fi, then you add in 2D graphics + LVGL and two partitions for OTA it was becoming an annoyance.

Because the current iteration was USB powered I decided to switch to the beefier ESP32-S3-WROOM-N8 with 8 MB Flash and 512 kB SRAM.

Long story short, you may need to turn features off or simplify them, especially RAM usage, if you switch to the ESP32-C3.

It'd be pretty time-intensive to review the entire schematic but keep me updated on the project! It'd be cool to see a mobile version. I'll consider a Discord in the future but I have bad experiences from too much noise from past Discord servers so I would probably not be active in it for now. Feel free to set up your own -- if it gets traction I can link to it in the README.

handmade0octopus, 2024-08-15:
Ok lets do it.

I created server, join and PM me Ill give you admin rights:
https://discord.gg/VAyvuMmuTU

As for the rest:
ESP32-S3 has 400kb SRAM and tbh I written big projects on smaller older ESP32 with colourful LVGL so it shouldn't be bottleneck. But I will look at codebase a bit later on and figure where it needs trimming.

Not sure if LVGL is right in case we don't use any button inputs - I think it could be simplified and boot button could be used to let users to change screens or configure changing of screens over WiFi (or controlled by HomeAssistant in similar way as ULANZI does).

We can try other bits or leave it as ESP32-S3 but in any case moving to platform.io would give us ability to have different builds for different versions/variants of the boards and people could submit them.

Lets try and see if there is interest on developing that.

handmade0octopus, 2024-09-11:
@babldev Though I will give you update: So far so good, made small mistake with one route but I managed to get most stuff working.
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
I only implemented screen, wifi, HDC1080 and SDC40.

Screen is fine, maximum 1.91 fps and I wrote driver for adafruid library so its much smaller and easier to use - can be easily adapted for LVGL.

Of course it uses C++ zero cost abstractions and still have most of RAM and flash available (with OTA updates).

Now writing MQTT broker to put data to home assistant, once that is ready I will think what to do next.

I have 2 problems that you may have encountered:
1. SDC40 drifts a LOT, temperature starts high and if I query in 30s mode it drops slowly to normal levels. Humidity though goes up and up all the time, also you can see it being hotter than the rest of the board (on thermal camera).

2. HDC1080 temperature seems to work well although it has offset like 2 degrees (with or without heater set). Humidity though keeps at 99.9% so not sure what to do there..

Not tested charging/battery yet as I am waiting for connectors but so far I am quite happy with this.

babldev, 2024-09-11:
@handmade0octopus Wow, super cool! Congrats on all your progress.

I had a _lot_ of problems with accurate temperature and humidity with the SHT4X. Specifically:
- The board heats up a few degrees, especially inside the enclosure
- Board heating also impacts relative humidity accuracy
- Humidity readings were way too high upon arrival, however I use the heater to to heat the sensor to 100 deg C for 4 hours and that seemed to correct whatever chemicals may have accumulated during board assembly / shipping from JLCPCB

FAQ note:
https://github.com/goat-hill/bitclock/blob/master/bitclock-web/src/app/(standard)/faq/page.mdx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

Board self heating adjustment:
https://github.com/goat-hill/bitclock/blob/f7410a7e918a6c5b4a211ab68c8a320072963e2e/bitclock-fw/main/tasks/sht4x.c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

Relative humidity adjustment:
https://github.com/goat-hill/bitclock/blob/f7410a7e918a6c5b4a211ab68c8a320072963e2e/bitclock-fw/main/tasks/sht4x.c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

handmade0octopus, 2024-09-16:
Thank you @babldev - I made some mistakes on switching off circuit and I think Ill get rid of it as wifi connection is too consuming anyway. But because of that I found some problems with ground.

Basically if I connect device with long cable or battery I think the ground connection isn't enough and this causes display to fail after ~1-2min (otherwise its fine).

I noticed you used 16V rated capacitor on C10 - but from my readings those lines go -20V and positive to +20V which I think may be bottleneck and I used similar setup (2x 2.2uF ones) so I think higher rated capacitor (50V) may solve this problem.

Not sure how temperature OTP code changes stuff but for now I hardcoded it at ~25°C.

Charging seems to be good, I think deep sleep mode may be better.

Will get respin on the board, still thinking if we need second humidity/temp sensor as I found with 30s time polling the main CO2 sensor seems to be good enough :)

Haven't tested NOx sensors yet though.

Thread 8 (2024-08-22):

Support MQTT or Home Assistant

runty, 2024-08-22:
This would also make it easy to import into other home platforms

babldev, 2024-08-22:
also requested by @glenrobertson

runty, 2024-08-28:
yes, automatically with graphing, many ways to show data, etc

manedfolf, 2024-09-28:
This would be an extremely powerful addition. +1

manedfolf, 2024-09-28:
It might be worth taking a look at the Aranet4's HA implementation as it actually uses Bluetooth (I think BLE specifically), granted this is only the HA half of that.

https://github.com/home-assistant/core/tree/dev/homeassistant/components/aranet
https://www.home-assistant.io/integrations/aranet/

It would be ideal to have this data accessible via both Wi-Fi and Bluetooth but I can understand if pursuing one option first would be simpler.

manedfolf, 2024-10-20:
@runty @glenrobertson If you are OK with forgoing display support in the interim, I have crafted an ESPHome config that allows you to run Bitclock with ESPHome firmware, sending data straight to Home Assistant.

https://github.com/manedfolf/bitclock/blob/esphome/bitclock-esphome/bitclock-esphome.yaml

It does not support the included display at this time since ESPHome doesn't have component support for the 2.71in Pervasive Displays E2271KS0C1 e-ink display. It would be possible to craft a custom component/driver for ESPHome, but that is admittedly not something I readily know how to do, but it would be very cool to be able to do custom screens directly within ESPHome. Granted, all of that is well outside of the scope of this project/repo so I have no expectation of support on this unless it piques the developer's interest.

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

babldev, 2024-10-20:
@manedfolf nice work!

Pretty amazing you can do that with just a few lines in a YAML file

babldev, 2024-10-20:
One thing to note is if you use direct sensor readings I assume you'll lose the "fudge factors" to correct temp + humidity.

https://github.com/goat-hill/bitclock/blob/d957f6439a1271d6ce122384d106790ee0d6c1c6/bitclock-fw/main/tasks/sht4x.c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

https://github.com/goat-hill/bitclock/blob/d957f6439a1271d6ce122384d106790ee0d6c1c6/bitclock-fw/main/tasks/sht4x.c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

manedfolf, 2024-10-20:
@babldev I can’t speak to the actual code behind it, but I believe the library does include configuration options for that kind of compensation

https://esphome.io/components/sensor/sht4x.html

glenrobertson, 2024-11-28:
@dogshapedangel I like the esphome solution you have! Before I discovered that, I put together these changes that will report data over MQTT in the homeassistant discovery message format: https://github.com/goat-hill/bitclock/pull/13

It would just need some changes to the web UI as well to accept an MQTT url.

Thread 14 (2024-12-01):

Reduce heap usage by using jsmn for weather API instead of cJSON

babldev, 2024-12-01:
cJSON uses 30kB of heap space for the api.weather.gov 17kB response, and this is very expensive making it difficult to add new features. Currently we only have about 3kB of headroom when parsing the response.

babldev, 2024-12-01:
discussion here https://github.com/goat-hill/bitclock/pull/13#issuecomment-2510305218

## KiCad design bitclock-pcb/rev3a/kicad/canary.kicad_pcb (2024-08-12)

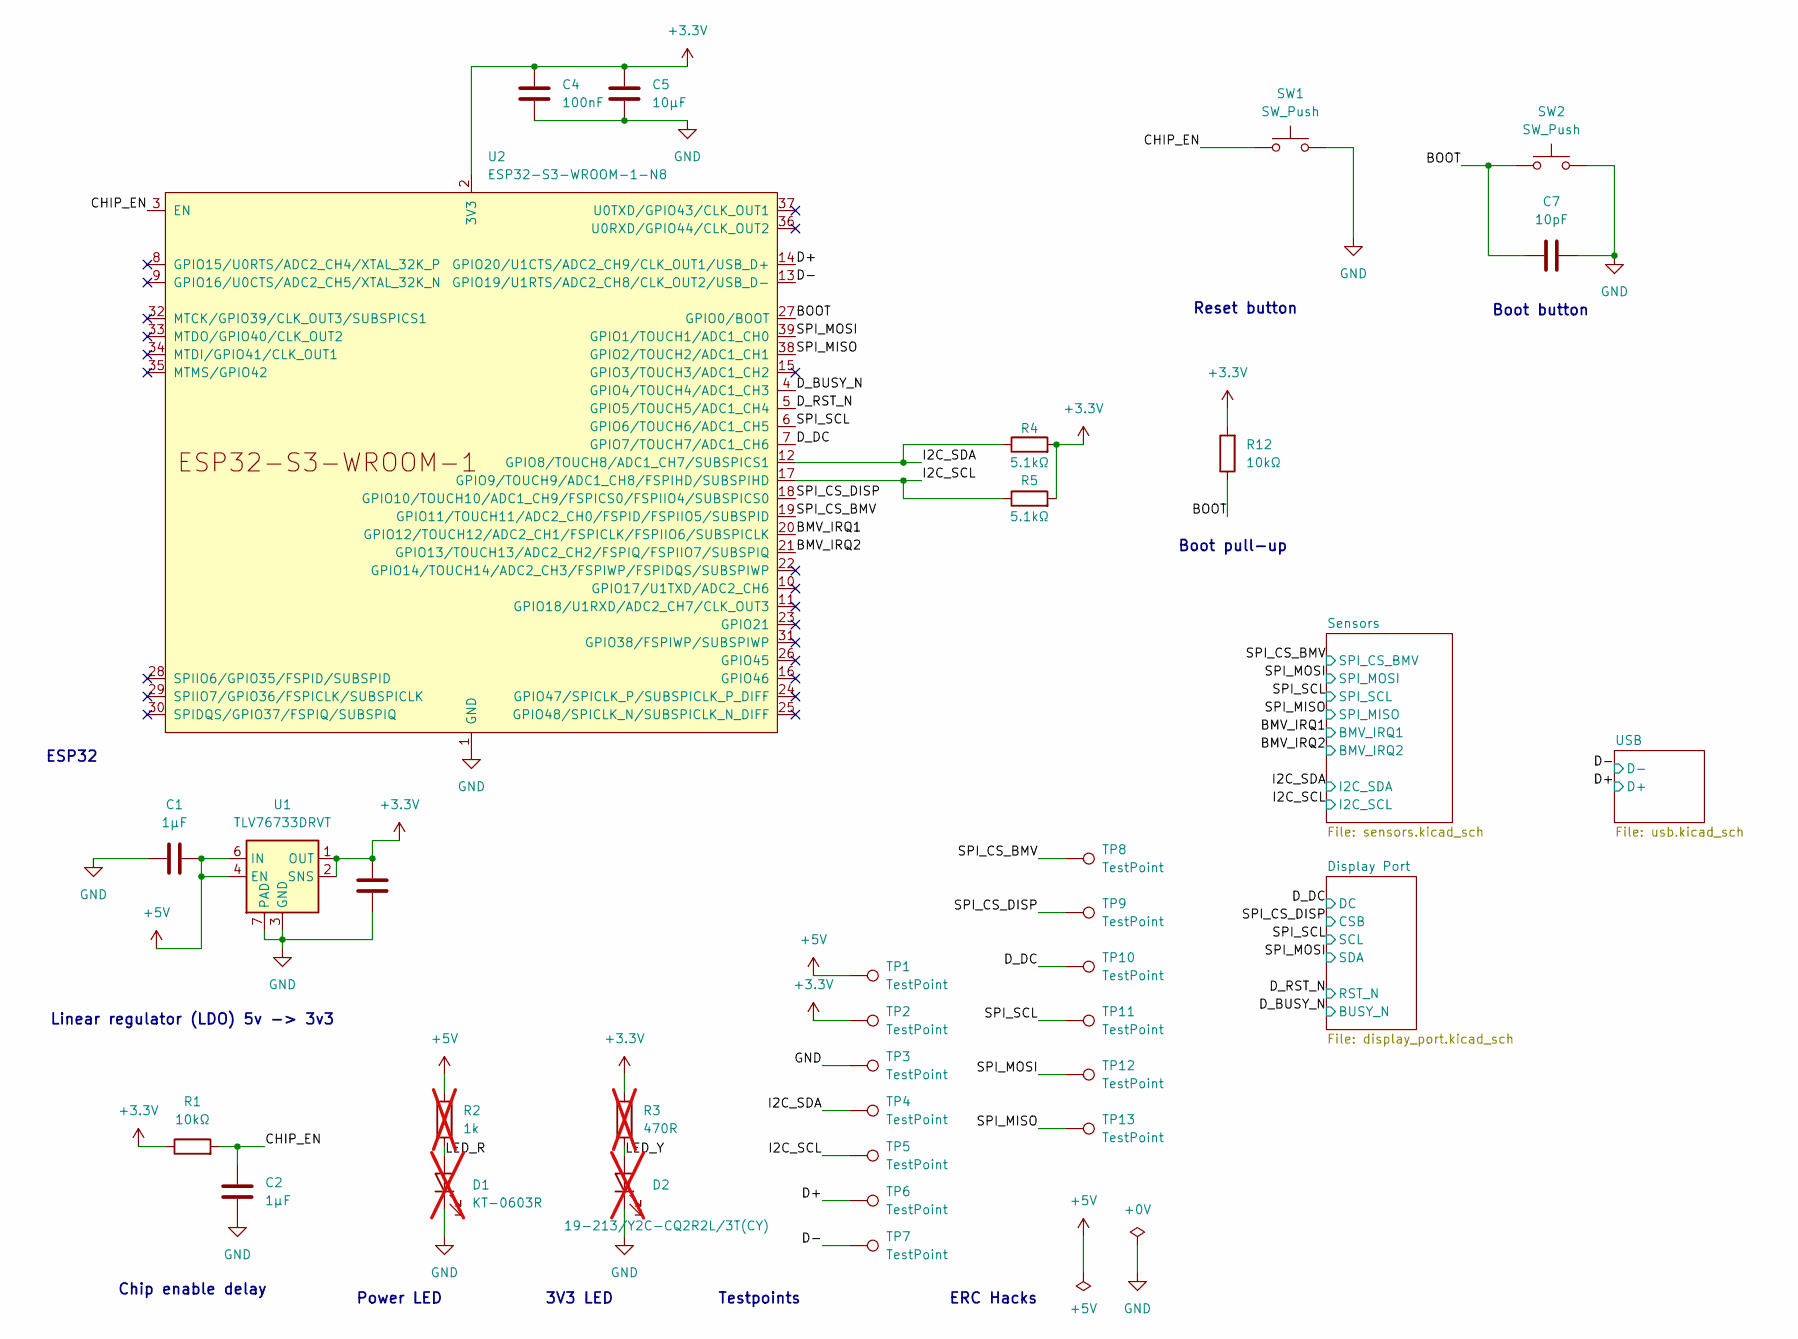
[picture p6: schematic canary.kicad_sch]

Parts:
C1, C2: 1µF; C_0402_1005Metric; JLCPCB Part # C52923
C3: 2.2µF; C_0603_1608Metric; JLCPCB Part # C23630
C4: 100nF; C_0402_1005Metric; JLCPCB Part # C1525
C5: 10µF; C_0603_1608Metric; JLCPCB Part # C96446
C7: 10pF; C_0402_1005Metric; JLCPCB Part # C32949
D1: KT-0603R; LED_0603_1608Metric; JLCPCB Part # C2286; not fitted
D2: 19-213/Y2C-CQ2R2L/3T(CY); LED_0603_1608Metric; JLCPCB Part # C72038; not fitted
R1, R12: 10kΩ; R_0402_1005Metric; JLCPCB Part # C25744
R2: 1k; R_0402_1005Metric; JLCPCB Part # C11702; not fitted
R3: 470R; R_0402_1005Metric; JLCPCB Part # C25117; not fitted
R4, R5: 5.1kΩ; R_0402_1005Metric; JLCPCB Part # C25905
SW1, SW2: SW_Push; SW_Push_1P1T_XKB_TS-1187A; JLCPCB Part # C318884
TP1, TP2, TP3, TP4, TP5, TP6, TP7, TP8, TP9, TP10, TP11, TP12, TP13: TestPoint; TestPoint_Pad_D1.5mm
U1: TLV76733DRVT; WSON-6-1EP_2x2mm_P0.65mm_EP1x1.6mm; JLCPCB Part # C2867572
U2: ESP32-S3-WROOM-1-N8; ESP32-S3-WROOM-1; JLCPCB Part # C2913198

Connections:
+3.3V: C3.2, C4.1, C5.1, R1.1, R3.1, R4.2, R5.2, R12.2, TP2.1, U1.1 (OUT), U1.2 (SNS), U2.2 (3V3); also elsewhere on the board
+5V: C1.2, R2.1, TP1.1, U1.4 (EN), U1.6 (IN); also elsewhere on the board
/BMV_IRQ1: U2.20 (GPIO12/TOUCH12/ADC2_CH1/FSPICLK/FSPIIO6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); also elsewhere on the board
/BMV_IRQ2: U2.21 (GPIO13/TOUCH13/ADC2_CH2/FSPIQ/FSPIIO7/S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); also elsewhere on the board
/BOOT: C7.1, R12.1, SW2.1, U2.27 (GPIO0/BOOT)
/CHIP_EN: C2.1, R1.2, SW1.1, U2.3 (EN)
/D+: TP6.1, U2.14 (GPIO20/U1CTS/ADC2_CH9/CLK_OUT1/USB_D+); also elsewhere on the board
/D-: TP7.1, U2.13 (GPIO19/U1RTS/ADC2_CH8/CLK_OUT2/USB_D-); also elsewhere on the board
/D_BUSY_N: U2.4 (GPIO4/TOUCH4/ADC1_CH3); also elsewhere on the board
/D_DC: TP10.1, U2.7 (GPIO7/TOUCH7/ADC1_CH6); also elsewhere on the board
/D_RST_N: U2.5 (GPIO5/TOUCH5/ADC1_CH4); also elsewhere on the board
/I2C_SCL: R5.1, TP5.1, U2.17 (GPIO9/TOUCH9/ADC1_CH8/FSPIHD/SUBSPIHD); also elsewhere on the board
/I2C_SDA: R4.1, TP4.1, U2.12 (GPIO8/TOUCH8/ADC1_CH7/SUBSPICS1); also elsewhere on the board
/LED_R: D1.2 (A), R2.2
/LED_Y: D2.2 (A), R3.2
/SPI_CS_BMV: TP8.1, U2.19 (GPIO11/TOUCH11/ADC2_CH0/FSPID/FSPIIO5/S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); also elsewhere on the board
/SPI_CS_DISP: TP9.1, U2.18 (GPIO10/TOUCH10/ADC1_CH9/FSPICS0/FSPIIO4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); also elsewhere on the board
/SPI_MISO: TP13.1, U2.38 (GPIO2/TOUCH2/ADC1_CH1); also elsewhere on the board
/SPI_MOSI: TP12.1, U2.39 (GPIO1/TOUCH1/ADC1_CH0); also elsewhere on the board
/SPI_SCL: TP11.1, U2.6 (GPIO6/TOUCH6/ADC1_CH5); also elsewhere on the board
GND: C1.1, C2.2, C3.1, C4.2, C5.2, C7.2, D1.1 (K), D2.1 (K), SW1.2, SW2.2, TP3.1, U1.3 (GND), U1.5 (GND), U1.7 (PAD), U2.1 (GND), U2.40 (GND), U2.41 (GND); also elsewhere on the board

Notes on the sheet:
ERC Hacks
Boot button
Boot pull-up
Chip enable delay
3V3 LED
Reset button
Power LED
Testpoints
ESP32
Linear regulator (LDO) 5v -> 3v3

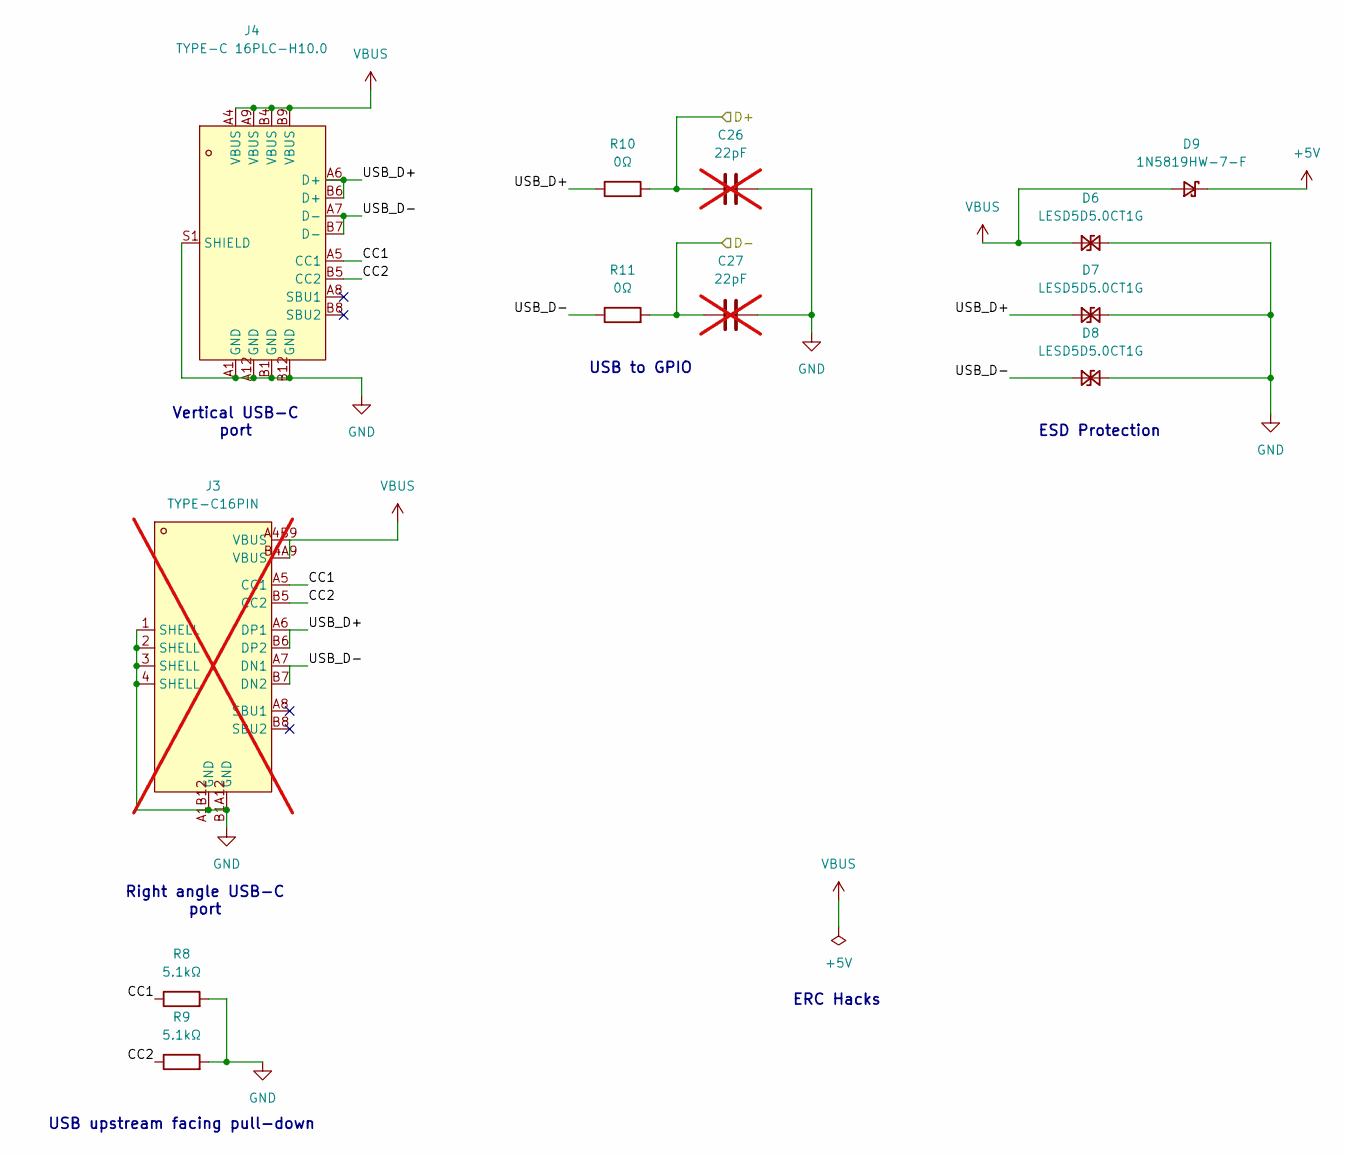
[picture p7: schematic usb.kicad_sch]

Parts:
C26, C27: 22pF; C_0402_1005Metric; not fitted
D6, D7, D8: LESD5D5.0CT1G; D_SOD-523; JLCPCB Part # C383211
D9: 1N5819HW-7-F; D_SOD-123; JLCPCB Part # C82544
J3: TYPE-C16PIN; USB-C-SMD_TYPE-C16PIN; LCSC Part C393939; not fitted
J4: TYPE-C 16PLC-H10.0; TYPE-C-TH_16PLC-H10.0; LCSC Part C3151747
R8, R9: 5.1kΩ; R_0402_1005Metric; JLCPCB Part # C25905
R10, R11: 0Ω; R_0402_1005Metric; JLCPCB Part # C17168

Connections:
+5V: D9.1 (K); also elsewhere on the board
/D+: C26.1, R10.2; also elsewhere on the board
/D-: C27.1, R11.2; also elsewhere on the board
/USB/CC1: J3.A5 (CC1), J4.A5 (CC1), R8.1
/USB/CC2: J3.B5 (CC2), J4.B5 (CC2), R9.1
/USB/USB_D+: D7.1 (A1), J3.A6 (DP1), J3.B6 (DP2), J4.A6 (D+), J4.B6 (D+), R10.1
/USB/USB_D-: D8.1 (A1), J3.A7 (DN1), J3.B7 (DN2), J4.A7 (D-), J4.B7 (D-), R11.1
GND: C26.2, C27.2, D6.2 (A2), D7.2 (A2), D8.2 (A2), J3.1 (SHELL), J3.2 (SHELL), J3.3 (SHELL), J3.4 (SHELL), J3.A1B12 (GND), J3.B1A12 (GND), J4.A1 (GND), J4.A12 (GND), J4.B1 (GND), J4.B12 (GND), J4.S1 (SHIELD), R8.2, R9.2; also elsewhere on the board
VBUS: D6.1 (A1), D9.2 (A), J3.A4B9 (VBUS), J3.B4A9 (VBUS), J4.A4 (VBUS), J4.A9 (VBUS), J4.B4 (VBUS), J4.B9 (VBUS)

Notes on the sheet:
ERC Hacks
Right angle USB-C port
Vertical USB-C port
ESD Protection
USB to GPIO
USB upstream facing pull-down

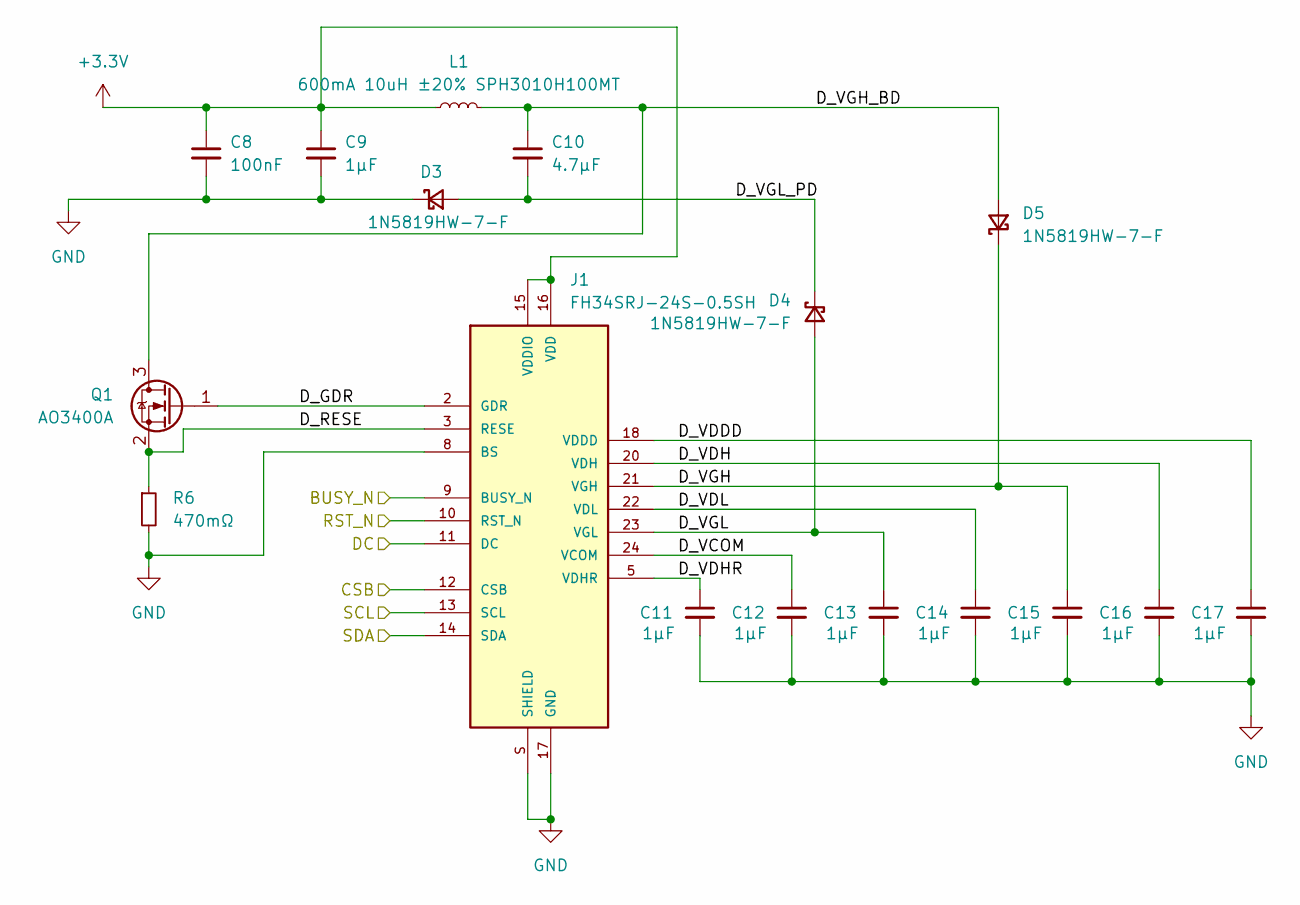
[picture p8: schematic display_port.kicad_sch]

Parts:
C8: 100nF; C_0402_1005Metric; JLCPCB Part # C1525
C9, C11, C12, C13, C14, C15, C16, C17: 1µF; C_0402_1005Metric; JLCPCB Part # C52923
C10: 4.7µF; C_0603_1608Metric; JLCPCB Part # C19666
D3, D4, D5: 1N5819HW-7-F; D_SOD-123; JLCPCB Part # C82544
J1: FH34SRJ-24S-0.5SH; HRS_FH34SRJ-24S-0.5SH_99_; PARTREV NA; JLCPCB Part # C324726
L1: 600mA 10uH ±20% SPH3010H100MT; L_Sunlord_SWPA3010S; JLCPCB Part # C279861
Q1: AO3400A; SOT-23; JLCPCB Part # C20917
R6: 470mΩ; R_0402_1005Metric; JLCPCB Part # C158958

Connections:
+3.3V: C8.1, C9.1, J1.15 (VDDIO), J1.16 (VDD), L1.1; also elsewhere on the board
/D_BUSY_N: J1.9 (BUSY_N); also elsewhere on the board
/D_DC: J1.11 (DC); also elsewhere on the board
/D_RST_N: J1.10 (RST_N); also elsewhere on the board
/Display Port/D_GDR: J1.2 (GDR), Q1.1 (G)
/Display Port/D_RESE: J1.3 (RESE), Q1.2 (S), R6.1
/Display Port/D_VCOM: C12.1, J1.24 (VCOM)
/Display Port/D_VDDD: C17.1, J1.18 (VDDD)
/Display Port/D_VDH: C16.1, J1.20 (VDH)
/Display Port/D_VDHR: C11.1, J1.5 (VDHR)
/Display Port/D_VDL: C14.1, J1.22 (VDL)
/Display Port/D_VGH: C15.1, D5.1 (K), J1.21 (VGH)
/Display Port/D_VGH_BD: C10.1, D5.2 (A), L1.2, Q1.3 (D)
/Display Port/D_VGL: C13.1, D4.2 (A), J1.23 (VGL)
/Display Port/D_VGL_PD: C10.2, D3.2 (A), D4.1 (K)
/SPI_CS_DISP: J1.12 (CSB); also elsewhere on the board
/SPI_MOSI: J1.14 (SDA); also elsewhere on the board
/SPI_SCL: J1.13 (SCL); also elsewhere on the board
GND: C8.2, C9.2, C11.2, C12.2, C13.2, C14.2, C15.2, C16.2, C17.2, D3.1 (K), J1.8 (BS), J1.17 (GND), J1.S (SHIELD), R6.2; also elsewhere on the board

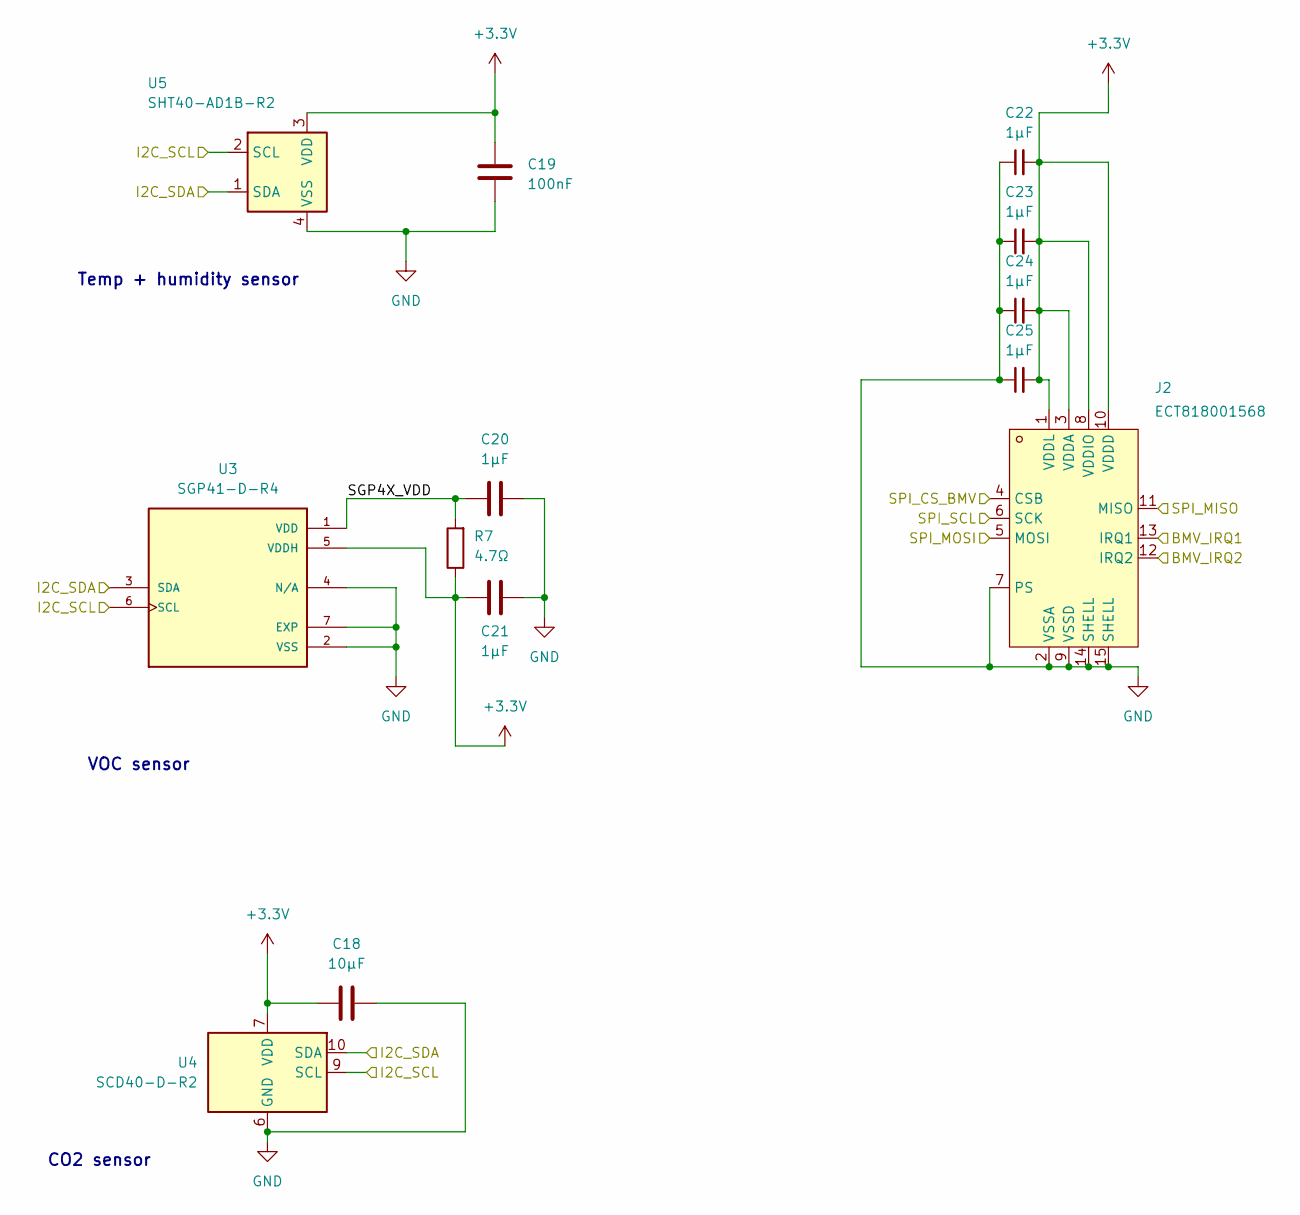
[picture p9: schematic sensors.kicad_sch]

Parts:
C18: 10µF; C_0603_1608Metric; JLCPCB Part # C96446
C19: 100nF; C_0402_1005Metric; JLCPCB Part # C1525
C20, C21, C22, C23, C24, C25: 1µF; C_0402_1005Metric; JLCPCB Part # C52923
J2: ECT818001568; FPC-SMD_ECT818001568; LCSC Part C711417
R7: 4.7Ω; R_0603_1608Metric; JLCPCB Part # C23164
U3: SGP41-D-R4; XDCR_SGP41-D-R4; PARTREV 1.0; JLCPCB Part # C3659325
U4: SCD40-D-R2; Sensirion_SCD4x-1EP_10.1x10.1mm_P1.25mm_EP4.8x4.8mm; JLCPCB Part # C3659421
U5: SHT40-AD1B-R2; Sensirion_DFN-4_1.5x1.5mm_P0.8mm_SHT4x_NoCentralPad; JLCPCB Part # C2909890

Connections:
+3.3V: C18.1, C19.2, C21.1, C22.2, C23.2, C24.2, C25.2, J2.1 (VDDL), J2.3 (VDDA), J2.8 (VDDIO), J2.10 (VDDD), R7.1, U3.5 (VDDH), U4.7 (VDD), U4.19 (VDD), U5.3 (VDD); also elsewhere on the board
/BMV_IRQ1: J2.13 (IRQ1); also elsewhere on the board
/BMV_IRQ2: J2.12 (IRQ2); also elsewhere on the board
/I2C_SCL: U3.6 (SCL), U4.9 (SCL), U5.2 (SCL); also elsewhere on the board
/I2C_SDA: U3.3 (SDA), U4.10 (SDA), U5.1 (SDA); also elsewhere on the board
/SPI_CS_BMV: J2.4 (CSB); also elsewhere on the board
/SPI_MISO: J2.11 (MISO); also elsewhere on the board
/SPI_MOSI: J2.5 (MOSI); also elsewhere on the board
/SPI_SCL: J2.6 (SCK); also elsewhere on the board
/Sensors/SGP4X_VDD: C20.1, R7.2, U3.1 (VDD)
GND: C18.2, C19.1, C20.2, C21.2, C22.1, C23.1, C24.1, C25.1, J2.2 (VSSA), J2.7 (PS), J2.9 (VSSD), J2.14 (SHELL), J2.15 (SHELL), U3.2 (VSS), U3.4 (N/A), U3.7 (EXP), U4.6 (GND), U4.20 (GND), U4.21 (GND), U5.4 (VSS); also elsewhere on the board

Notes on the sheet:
VOC sensor
Temp + humidity sensor
CO2 sensor

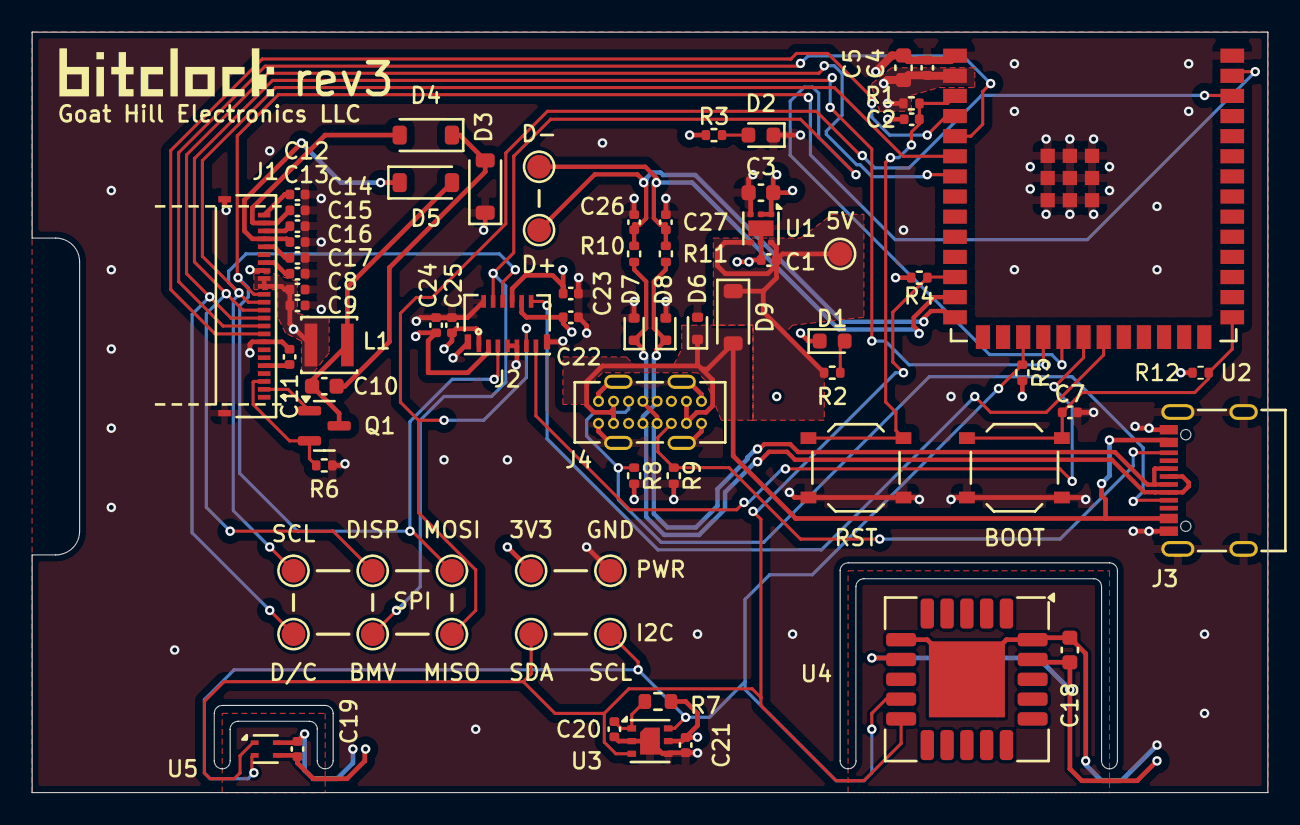
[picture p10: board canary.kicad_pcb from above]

Board: 4 copper layers, 78.0 x 48.0 mm, 74 parts (1 on the bottom side), 38 nets.

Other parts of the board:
EINK1: EInk_Display_2.71_E2271KS0C1

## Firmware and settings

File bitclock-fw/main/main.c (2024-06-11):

#include <stdio.h>
#include <stdlib.h>
#include <time.h>

#include "driver/gpio.h"
#include "driver/spi_master.h"
#include "esp_log.h"
#include "freertos/FreeRTOS.h"
#include "freertos/task.h"

#include "libs/i2c.h"
#include "libs/nvs.h"
#include "libs/ota.h"
#include "nvs_flash.h"
#include "pins.h"

#include "tasks/ble.h"
#include "tasks/eink_display.h"
#include "tasks/led.h"
#include "tasks/scd4x.h"
#include "tasks/sgp4x.h"
#include "tasks/sharp_display.h"
#include "tasks/sht4x.h"
#include "tasks/tasks.h"
#include "tasks/weather.h"
#include "tasks/wifi.h"

void app_main(void) {
  ESP_ERROR_CHECK(bitclock_ota_on_boot());
  i2c_bus_init();

  // Used by wifi, ble tasks
  esp_err_t ret = nvs_flash_init();
  if (ret == ESP_ERR_NVS_NO_FREE_PAGES ||
      ret == ESP_ERR_NVS_NEW_VERSION_FOUND) {
    /* NVS partition was truncated
     * and needs to be erased */
    ESP_ERROR_CHECK(nvs_flash_erase());
    ESP_ERROR_CHECK(nvs_flash_init());
  }
  ESP_ERROR_CHECK(ret);
  ESP_ERROR_CHECK(bitclock_nvs_init());

  const char *tz = bitclock_nvs_get_tz();
  if (tz != NULL) {
    setenv("TZ", tz, 1);
    tzset();
  } else {
    setenv("TZ", "PST8PDT,M3.2.0,M11.1.0", 1);
    tzset();
  }

#ifdef LED_TASK_ENABLED
  ledTask = xTaskCreateStatic(led_task_run, "led",
                              LED_STACK_SIZE,    // ulStackDepth
                              (void *)1,         // pvParamters
                              LED_TASK_PRIORITY, // uxPriority
                              ledTaskStack,      // puxStackBuffer
                              &ledTaskBuffer     // pxTaskBuffer
  );
#endif

#ifdef DISP_TASK_ENABLED
#if DISPLAY_TYPE == DISPLAY_TYPE_SHARP
  dispTask = xTaskCreateStatic(disp_task_run, "display",
                               DISP_STACK_SIZE,    // ulStackDepth
                               (void *)1,          // pvParamters
                               DISP_TASK_PRIORITY, // uxPriority
                               dispTaskStack,      // puxStackBuffer
                               &dispTaskBuffer     // pxTaskBuffer
  );
#elif DISPLAY_TYPE == DISPLAY_TYPE_EINK
  einkTask = xTaskCreateStatic(eink_task_run, "eink",
                               EINK_STACK_SIZE,    // ulStackDepth
                               (void *)1,          // pvParamters
                               EINK_TASK_PRIORITY, // uxPriority
                               einkTaskStack,      // puxStackBuffer
                               &einkTaskBuffer     // pxTaskBuffer
  );
#endif
#endif // DISP_TASK_ENABLED

#ifdef SHT4X_TASK_ENABLED
  sht4xTask = xTaskCreateStatic(sht4x_task_run, "sht4x",
                                SHT4X_STACK_SIZE,    // ulStackDepth
                                (void *)1,           // pvParamters
                                SHT4X_TASK_PRIORITY, // uxPriority
                                sht4xTaskStack,      // puxStackBuffer
                                &sht4xTaskBuffer     // pxTaskBuffer
  );
#endif

#ifdef SCD4X_TASK_ENABLED
  scd4xTask = xTaskCreateStatic(scd4x_task_run, "scd4x",
                                SCD4X_STACK_SIZE,    // ulStackDepth
                                (void *)1,           // pvParamters
                                SCD4X_TASK_PRIORITY, // uxPriority
                                scd4xTaskStack,      // puxStackBuffer
                                &scd4xTaskBuffer     // pxTaskBuffer
  );
#endif

#ifdef SGP4X_TASK_ENABLED
  sgp4xTask = xTaskCreateStatic(sgp4x_task_run, "scd4x",
                                SGP4X_STACK_SIZE,    // ulStackDepth
                                (void *)1,           // pvParamters
                                SGP4X_TASK_PRIORITY, // uxPriority
                                sgp4xTaskStack,      // puxStackBuffer
                                &sgp4xTaskBuffer     // pxTaskBuffer
  );
#endif

#ifdef WIFI_TASK_ENABLED
  wifiTask = xTaskCreateStatic(wifi_task_run, "wifi",
                               WIFI_STACK_SIZE,    // ulStackDepth
                               (void *)1,          // pvParamters
                               WIFI_TASK_PRIORITY, // uxPriority
                               wifiTaskStack,      // puxStackBuffer
                               &wifiTaskBuffer     // pxTaskBuffer
  );
#endif

#ifdef BLE_TASK_ENABLED
  bleTask = xTaskCreateStatic(ble_task_run, "ble",
                              BLE_STACK_SIZE,    // ulStackDepth
                              (void *)1,         // pvParamters
                              BLE_TASK_PRIORITY, // uxPriority
                              bleTaskStack,      // puxStackBuffer
                              &bleTaskBuffer     // pxTaskBuffer
  );
#endif

#ifdef WEATHER_TASK_ENABLED
  weatherTask = xTaskCreateStatic(weather_task_run, "weather",
                                  WEATHER_STACK_SIZE,    // ulStackDepth
                                  (void *)1,             // pvParamters
                                  WEATHER_TASK_PRIORITY, // uxPriority
                                  weatherTaskStack,      // puxStackBuffer
                                  &weatherTaskBuffer     // pxTaskBuffer
  );
#endif

  assert(gpio_install_isr_service(0) == ESP_OK);

  vTaskDelete(NULL);
}

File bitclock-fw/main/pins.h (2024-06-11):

#include "driver/gpio.h"
#include "soc/gpio_num.h"

// 0 - breadboard
// 1 - rev1 PCB
// 2 - rev2 PCB

#define DISPLAY_TYPE_EINK 1
#define DISPLAY_TYPE_SHARP 2

#ifndef BOARD_TARGET
// Need this until VSCode define settings work
#define BOARD_TARGET 2
#endif

//
// SPI + Display
//

#if BOARD_TARGET == 0
#define DISPLAY_TYPE DISPLAY_TYPE_SHARP
#else
#define DISPLAY_TYPE DISPLAY_TYPE_EINK
#endif

#if BOARD_TARGET >= 2
#define DISPLAY_ROTATION -90
#elif BOARD_TARGET == 1
#define DISPLAY_ROTATION 90
#else
#define DISPLAY_ROTATION 0
#endif

#if BOARD_TARGET >= 2

#define PIN_NUM_SPI_MOSI GPIO_NUM_1
#define PIN_NUM_SPI_MISO GPIO_NUM_2
#define PIN_NUM_SPI_CLK GPIO_NUM_6
#define PIN_NUM_SPI_CS_DISP GPIO_NUM_10
#define PIN_NUM_DISP_BUSY GPIO_NUM_4
#define PIN_NUM_DISP_RST GPIO_NUM_5
#define PIN_NUM_DISP_DC GPIO_NUM_7

#define PIN_NUM_SPI_CS_BMV GPIO_NUM_10
#define PIN_NUM_SPI_BMV_IRQ1 GPIO_NUM_12
#define PIN_NUM_SPI_BMV_IRQ2 GPIO_NUM_13

#elif BOARD_TARGET == 1

#define PIN_NUM_SPI_MOSI GPIO_NUM_7
#define PIN_NUM_SPI_CLK GPIO_NUM_6
#define PIN_NUM_SPI_CS_DISP GPIO_NUM_18
#define PIN_NUM_DISP_BUSY GPIO_NUM_0
#define PIN_NUM_DISP_RST GPIO_NUM_1
#define PIN_NUM_DISP_DC GPIO_NUM_19

#elif BOARD_TARGET == 0

#define PIN_NUM_SPI_MOSI GPIO_NUM_7
#define PIN_NUM_SPI_CLK GPIO_NUM_8
#define PIN_NUM_SPI_CS_DISP GPIO_NUM_44

#endif

//
// I2C
//
#if BOARD_TARGET == 2
#define PIN_NUM_I2C_SDA GPIO_NUM_8
#define PIN_NUM_I2C_SCL GPIO_NUM_9
#elif BOARD_TARGET == 1
#define PIN_NUM_I2C_SDA GPIO_NUM_4
#define PIN_NUM_I2C_SCL GPIO_NUM_5
#elif BOARD_TARGET == 0
#define PIN_NUM_I2C_SDA GPIO_NUM_43
#define PIN_NUM_I2C_SCL GPIO_NUM_6
#endif

#if BOARD_TARGET == 0
#define I2C_REQUIRES_PULLUP 1
#else
#define I2C_REQUIRES_PULLUP 0
#endif

//
// User LED
//
#if BOARD_TARGET == 0
#define PIN_NUM_BLINK GPIO_NUM_21
#endif

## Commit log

2024-06-13 update enclosure
    [Back plastic.stl, Front plastic.stl, back.stl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]
2024-06-13 version update
    [back.stl, front.stl]
2024-08-12 open source rev3a PCB
    [bom-jlcpcb.csv, bom.csv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]
2024-08-15 update sensor accuracy FAQ
2025-10-27 update idf, linux case sensitive filesystem fix
2026-09-25 Upgrade web to Next 16 / React 19 to fix audit vulnerabilities
    - next 14 -> 16, react 18 -> 19, @next/mdx 16, Mantine 7.17, sharp 0.35,
    Stripe JS/React for React 19, ESLint 9 flat config (next lint removed)
    - Replace symlinked og/twitter images with copies (Turbopack resolves
    both symlinks to the same path and fails the build)
    - Pass a "use client" re-export of next/link to Mantine `component`
    props from server components (required by React 19)
    npm audit: 8 vulnerabilities -> 0
